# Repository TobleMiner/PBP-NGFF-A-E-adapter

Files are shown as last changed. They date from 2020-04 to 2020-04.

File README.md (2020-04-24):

Pinebook Pro M.2 WiFi adapter
=============================

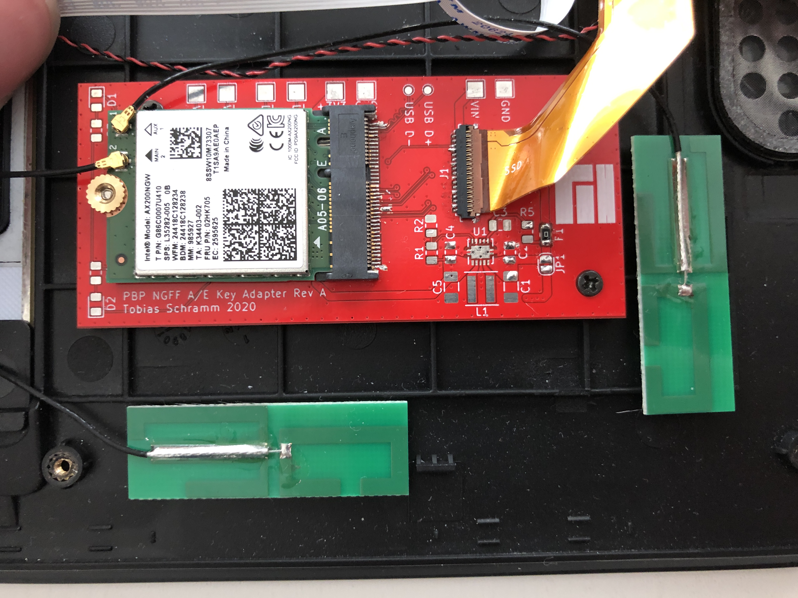
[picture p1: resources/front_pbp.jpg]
PCB inside Pinebook


#### Overview

The M.2 A/E key adapter enables the use of M.2 WiFi cards in the Pinebook Pro ARM laptop.  

This adapter was designed as a replacement for the available [NVMe M.2 (M-key) adapter](https://store.pine64.org/?product=pinebook-pro-m-2ngff-nvme-ssd-interface-adapter).  
It uses the same flat flex cable, mounting screws and mounting position. 

USB is not present on the PBP FFC and needs to be connected manually if required.  
Test points for D- and D+ are present on the PCB.  
Most WiFi+Bluetooth combo cards use USB for Bluetooth, but the PBPs internal UART HCI bluetooth adapter can still be used, even after disabling the SDIO WiFi kernel module.  

#### Tested cards

All testing was done using Manjaro ARM, kernel 5.6 and 5.7-rc1. 

Card | Test result
--- | ---
Intel AX200NGW | Works very well, stable, requires additional firmware.
Atheros QCA6174A | Kernel panic at boot, not recommended.

Pull requests with additional test results welcome. 

#### Bill of materials

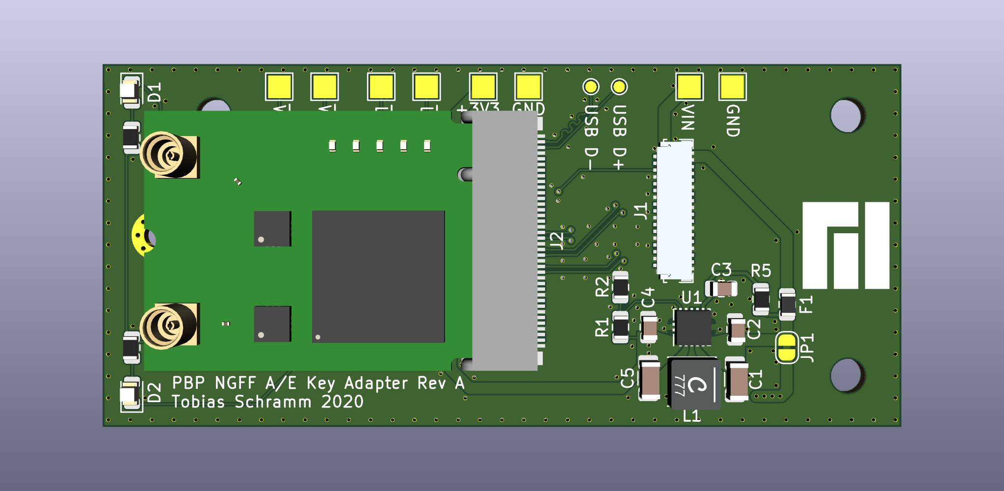
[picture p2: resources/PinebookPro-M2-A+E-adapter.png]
PCB top


The board offers an additional footprint for a switch-mode regulator to guarantee a stable 3.3V supply for the M.2 card. 
In our testing this wasn't required and can be left unpopulated. The only required components are the 2 connectors and either a 0805 SMD fuse or 0 ohm resistor at F1.

The PCB should be manufactured as a **1.0mm thick** FR4 board. 

[Interactive BOM](https://tobleminer.github.io/PBP-NGFF-A-E-adapter/ibom.html)

| Design. | Description | Part No. | Links  |
| ----- |:---:|:---:| -----:|
| J1 | FFC conn. | Hirose FH26W-35S-0.3SHW | [Datasheet](https://www.mouser.de/datasheet/2/185/FH26_CL0580-2410-2-60_2d-1614872.pdf) \| [Mouser](https://www.mouser.de/ProductDetail/hirose-electric/fh26w-35s-03shw60/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) |
| J2 | M.2 E-key | Amphenol MDT275E02001 | [Datasheet](https://www.mouser.de/datasheet/2/18/Amphenol_CMDTXXXXXX001-4-1157232.pdf) \| [Mouser](https://www.mouser.de/ProductDetail/fci-amphenol/mdt275e02001/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)  |
| - | Dual-band MHF4 antenna | Laird EMN2449R1S-8MHF4 | [Mouser](https://www.mouser.de/ProductDetail/laird-connectivity/emn2449r1s-8mhf4/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)

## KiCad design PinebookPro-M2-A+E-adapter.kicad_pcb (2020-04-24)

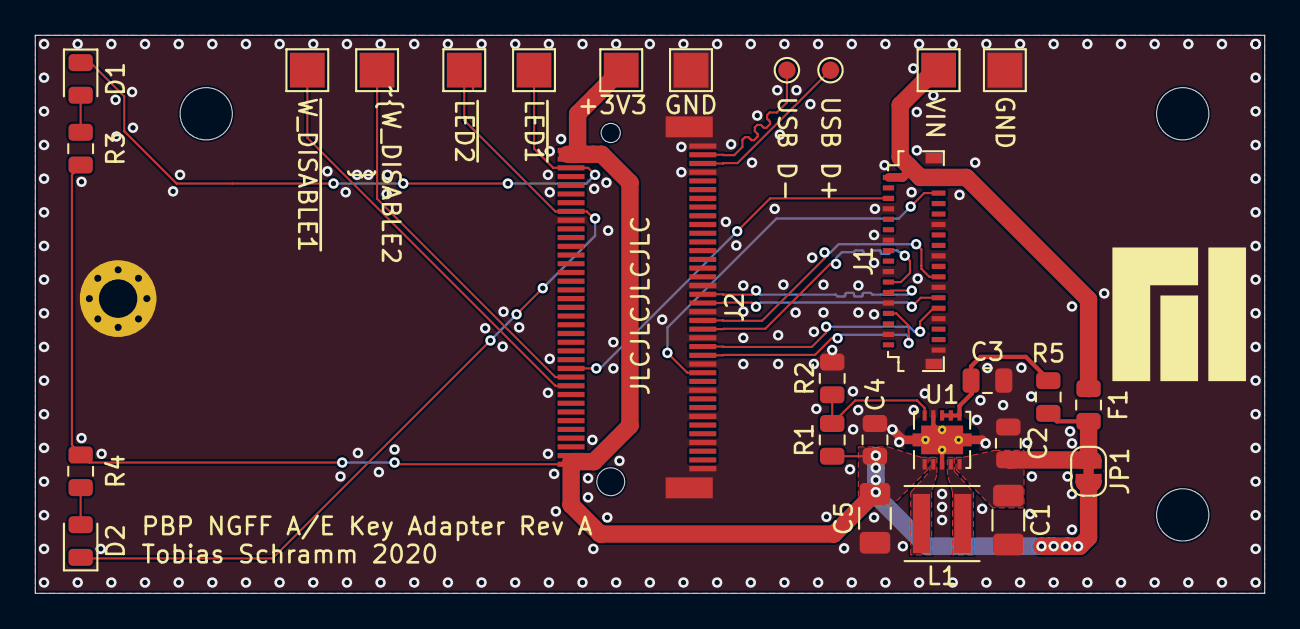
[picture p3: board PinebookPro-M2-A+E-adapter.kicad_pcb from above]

Board: 2 copper layers, 70.5 x 32.0 mm, 29 parts (0 on the bottom side), 24 nets.

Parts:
C1, C5: DNP; C_1206_3216Metric
C2, C4: 10 µF; C_0805_2012Metric
C3: 100 nF; C_0805_2012Metric
D1, D2: LED; LED_0805_2012Metric
F1: 2 A; Fuse_0805_2012Metric
H1: MountingHole_Pad; MountingHole_2.2mm_M2_Pad_Via
J1: Conn_01x35_MountingPin; Hirose_FH26-35S-0.3SH_2x35-1MP_P0.30mm_Horizontal
J2: M.2-NGFF-A+E-Key; MDTXXXXXX001
JP1: SolderJumper_2_Bridged; SolderJumper-2_P1.3mm_Bridged_RoundedPad1.0x1.5mm
L1: 2.2 µH; L_Coilcraft_XxL4020
R1: 0 R; R_0805_2012Metric
R2: DNP; R_0805_2012Metric
R3, R4: 330 R; R_0805_2012Metric
R5: 100 R; R_0805_2012Metric
TP1, TP2: TestPoint; TestPoint_Pad_D1.0mm
TP3, TP4, TP5, TP6, TP7, TP8, TP9, TP10: TestPoint; TestPoint_Pad_2.0x2.0mm
U1: TPS63001; Texas_DRC0010J_ThermalVias

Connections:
+3V0: F1.2, J1.33, J1.34, J1.35, TP8.1
+3V3: C4.1, C5.1, J2.2, J2.4, J2.72, J2.74, JP1.2, R1.1, R3.1, R4.1, TP7.1, U1.1
/REFCLK+: J1.9, J2.47
/REFCLK-: J1.8, J2.49
/RX+: J1.15, J2.41
/RX-: J1.14, J2.43
/TX+: J1.12, J2.35
/TX-: J1.11, J2.37
/USB_D+: J2.3, TP2.1
/USB_D-: J2.5, TP1.1
/~CLKREQ: J1.31, J2.53
/~LED1: D1.1, J2.6, TP5.1
/~LED2: D2.1, J2.16, TP6.1
/~PERST: J1.30, J2.52
/~W_DISABLE1: J2.56, TP3.1
/~W_DISABLE2: J2.54, TP4.1
GND: C1.2, C2.2, C3.2, C4.2, C5.2, H1.1, J1.1, J1.4, J1.7, J1.10, J1.13, J1.16, J1.19, J1.22, J1.25, J1.28, J1.MP, J2.1, J2.7, J2.18, J2.33, J2.39, J2.45, J2.51, J2.57, J2.63, J2.69, J2.75, J2.MP, R2.2, TP9.1, TP10.1, U1.3, U1.9, U1.11
unnamed: C1.1, C2.1, F1.1, JP1.1, R5.1, U1.5
unnamed: C3.1, R5.2, U1.6, U1.7, U1.8
unnamed: D1.2, R3.2
unnamed: D2.2, R4.2
unnamed: L1.1, U1.4
unnamed: L1.2, U1.2
unnamed: R1.2, R2.1, U1.10

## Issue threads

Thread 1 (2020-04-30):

Add support for the Quectel LTE EC25 with a SIM slot

NostalgiaRunner, 2020-04-30:
Hello,

I love the work that I'm seeing here and look forward to fabricating my own board for my Pinebook Pro. That said, I was wondering if you could please make a second revision for those who wish to add cellular capabilities to their Pinebook. Currently the Quectel LTE EC25 is being utilized in the Pine ecosystem in the Pinephone, and I think it would make a great addition to the Pinebook for those on the go. I don't know how much the board components would have to be rearranged to add a SIM slot, but I know I'm not the only one who'd appreciate it.

Thank you.

TobleMiner, 2020-05-08:
Hi,

> I was wondering if you could please make a second revision for those who wish to add cellular capabilities to their Pinebook

That would be possible. I should be able to squeeze a nano SIM socket on there.

> Currently the Quectel LTE EC25 is being utilized in the Pine ecosystem in the Pinephone

While that is true the Quectel LTE EC25 is a module designed to be soldered onto a PCB. I'd like to use just a M.2 B-Key socket since it could then be used with any M.2 LTE modem.

NostalgiaRunner, 2020-05-09:
Awesome! Thank you! And yes, I agree, just an M.2 slot or a Mini PCIe would work great. Though to clarify, I have only seen the EC25 as a Mini PCIe module in the prototyping photos and in my searches on eBay, and that is what I had meant. Having to solder on a modem would be a pain and a half. :smile: Best of luck, and stay safe!

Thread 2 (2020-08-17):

how to install?

alexr4535, 2020-08-17:
I special ordered your adapter from a 3rd party company using your BOM / kicad. I also ordered the Intel Dual Band Wireless AX200NGW 2.4Gbps 802.11ax Wireless Intel AX200 WiFi Card and some M.2 NGFF Antenna,Pair of IPEX MHF4 2.4G/5G Dual Band 6dbi Gain WiFi Antennas. from the readme it says some special firmware is needed, how can i find and flash that firmware? also, what else is needed to run the new wireless card once everything is installed? does it Just Work, or does the old wifi card need to be removed?

Manawyrm, 2020-08-17:
HI!

Everything should just work fine, out of the box. The information about the firmware is a bit old.
You should make sure your Manjaro installation is up to date (the package linux-firmware is the important one).

You can disable the integrated WiFi module by blacklisting the kernel module (`blacklist brcmfmac`), if you want.

Good luck!

alexr4535, 2020-12-15:
@Manawyrm Is this a viable alternative to the FFC conn. listed in the BOM?
The company i used "Lion Circuits" can't find the one you've listed.
https://www.mouser.com/ProductDetail/TE-Connectivity/1-1734592-9/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

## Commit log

2020-03-28 Add GND testpoints
    [PinebookPro-M2-A+E-adapter.kicad_pcb, PinebookPro-M2-A+E-adapter.sch]
2020-03-28 Add VINA strapping resistor
    [PinebookPro-M2-A+E-adapter.kicad_pcb, PinebookPro-M2-A+E-adapter.sch]
2020-03-31 Rev A
    [PinebookPro-M2-A+E-adapter.kicad_pcb]
2020-04-24 Add bom
    [PinebookPro-M2-A+E-adapter.kicad_pcb, PinebookPro-M2-A+E-adapter.sch]
2020-04-24 Add photo of board
2020-04-24 Add recommended antenna to BOM
